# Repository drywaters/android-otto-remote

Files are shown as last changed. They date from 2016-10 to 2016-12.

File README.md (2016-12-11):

# OttoRemote

Piece Designs and other Additional Files - Includes the 3D design pieces supplied by Otto.strikingly.com.
Included in that directory is the Leg File that I designed and other documentation from their own website.

Otto_Arduino - Is the Arduino app that we created that uses the Bluetooth as a controller.

OTTO_smooth_criminal - Is an Arduino app created by somebody else that allows Otto to just dance.

The rest of the files is the actual Bluetooth app that works with BLUNO microcontrollers.

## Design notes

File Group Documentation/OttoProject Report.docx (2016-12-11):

Team Members:

Samuel Lum

Luan Dinh

Daniel Waters

Abstract

Title:

Otto the Robot

Problem:

Allow the user to remotely control a 3D printed Otto Robot using an Android app and a Bluetooth serial connection. The user is given options through the app to move forward, backwards, left, right, or play sound. The robot will sense objects in front of it, and refuse to move forward if something is within 5cm in front of it.

Techniques used:

1. Print the pieces of the robot using a 3D printer.
2. Wire electrical circuits to function correctly with an Arduino Mini microcontroller.
3. Allow the user to connect/disconnect to a Bluetooth radio in the Otto Robot through an Android application.
4. Once a command is received from the user, control the movements of the robot by 4 servo motors placed inside Otto.
5. Detect the distance in front of the robot using an ultrasonic sensor, and decide to move forward based on returned distance.
6. Allow Otto to make sound using a connected buzzer.
7. The Android application was written in Java using Android Studio, and the Arduino sketch was written in C/C++ using Arduino IDE.

Team Members:

Samuel Lum

Luan Dinh

Daniel Waters

Project: Otto the Robot

Objectives:

- Quick explanation of what the Otto the Robot is.
- Give a quick overview of how a 3D printer works.
- Explain how the Android application works.
- Use a GUI for the user to communicate with Otto
- Techniques used:
  - 3D design a new leg to connect correctly
  - 3D printed the parts
  - GUI for the Android application
  - Serial Bluetooth connection between phone and Arduino

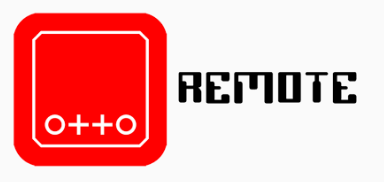
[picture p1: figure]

Otto the Robot is:

Otto, is an open source design for a robot found at http://otto.strikingly.com. The website supplies 3D printer design files for the pieces needed to build the robot and electrical wiring diagrams. It also includes a PDF that takes the user step by step in the build process. While the outer shell of Otto is given, the abilities for Otto is left up to the user to design themselves.

3D Design

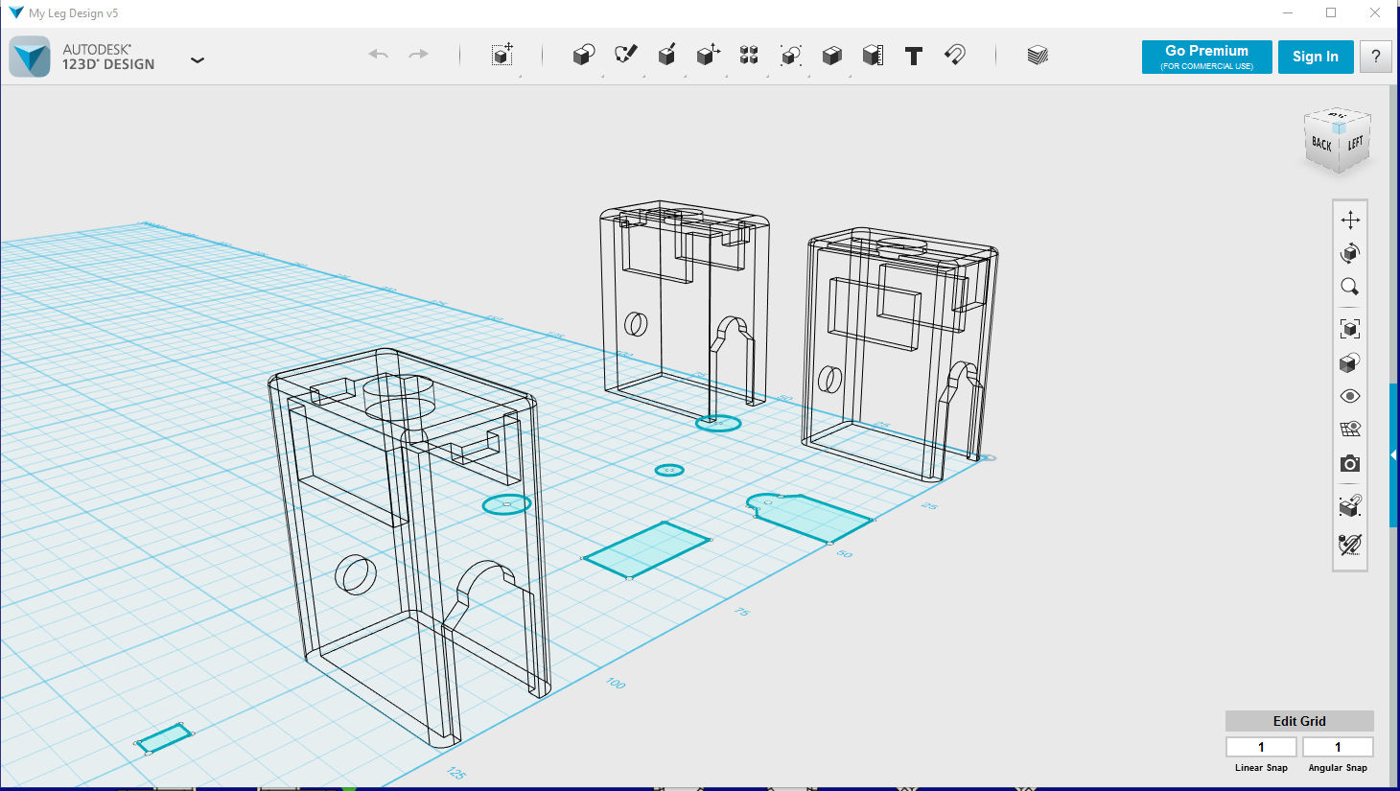
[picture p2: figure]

A 3D printer prints files that are designed in a 3D software such as Autodesk 123D Design. Inside this program a designer uses basic shapes to mold a shape into something that the printer would be able to understand. Example in this picture a simple box has pieces removed from it to form the shape of the newly designed Otto leg that will fit with the servos purchased. In the background are different versions of the leg that did not work correctly.

Once the figure is complete, it is exported to another software program that takes the 3D object and slices it into 100’s or 1000’s of tiny layers that the printer will use to build the object layer on layer. The program that I am using here is called FlashForge FlashPrint. For this simple leg at a standard quality it slices it down to 217 layers that needs to be printed.

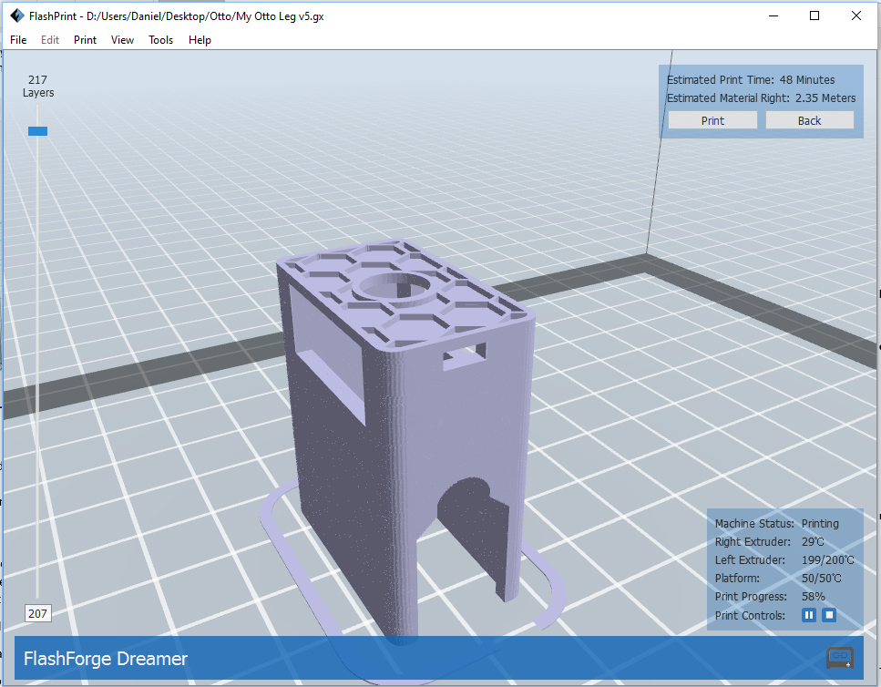
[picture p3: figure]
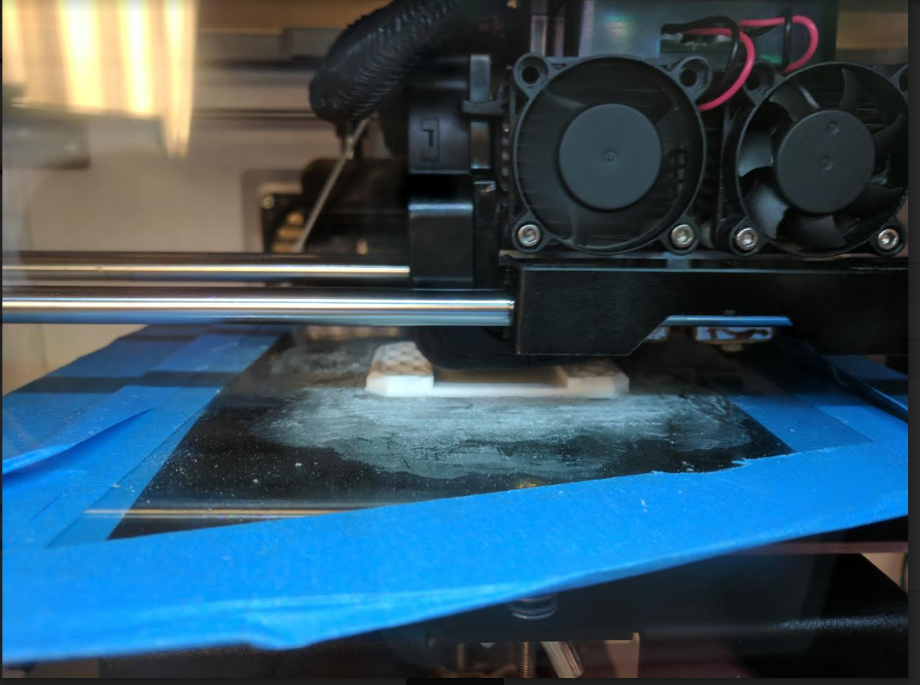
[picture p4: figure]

Finally, the printer understands the layers, and builds the object layer upon layer heating up plastic and printing them with small droplets of plastic.

Otto the Robot - Parts Schematic

Parts and Wiring Diagram for the Otto Robot

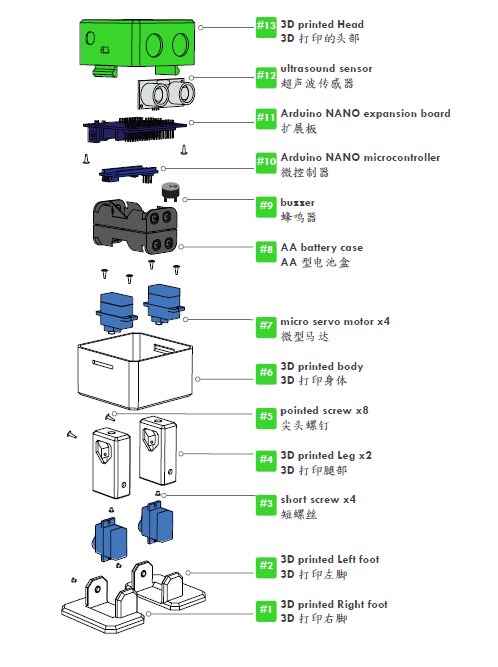
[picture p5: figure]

Otto the Robot – Wiring Diagram

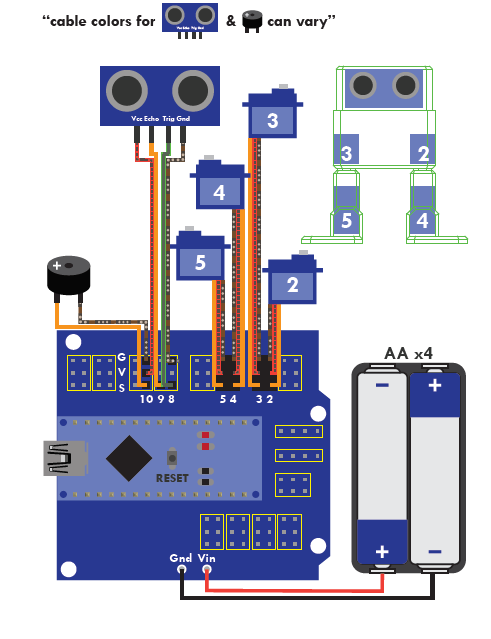
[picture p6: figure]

Parts Needed:

1x - Arduino Nano R3 Bluetooth embedded - https://www.dfrobot.com/index.php?route=product/product&product_id=1122 (https://www.google.com/url?amp;sa=D&amp;ust=1477184990057000&amp;usg=AFQjCNEKTpgmWJndd0WFRKf9GHzIdCvTMQ)

1x - Arduino Nano Shield I/O -

https://www.amazon.com/Solu-Expansion-Sensor-Arduino-Compatible/dp/B00UBEHJUO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 (https://www.google.com/url?amp;sa=D&amp;ust=1477184990058000&amp;usg=AFQjCNF9IKG_SzKIB6bwvJT9f6koBEpQsA)

1x - USB-A to Micro USB Cable -

https://www.amazon.com/gp/product/B012A1ML6W/ref=oh_aui_detailpage_o02_s00?ie=UTF8&psc=1 (https://www.google.com/url?amp;sa=D&amp;ust=1477184990059000&amp;usg=AFQjCNH3zjUvan4TNBtP3k6qlCdaCycngQ)

1x - HC-SR04 Ultrasound Sensor -

https://www.amazon.com/gp/product/B004U8TOE6/ref=oh_aui_detailpage_o03_s01?ie=UTF8&psc=1 (https://www.google.com/url?amp;sa=D&amp;ust=1477184990060000&amp;usg=AFQjCNFkso1mr9lOPCX5DlcGTcIGxcjSXw)

4x - Mini Servo SG90 9g -

https://www.amazon.com/gp/product/B01608II3Q/ref=oh_aui_detailpage_o03_s01?ie=UTF8&psc=1 (https://www.google.com/url?amp;sa=D&amp;ust=1477184990061000&amp;usg=AFQjCNHuSwTF9lRWxEb-zCN-XNy2eGt7uQ)

1x - Buzzer -

https://octopart.com/1536-adafruit+industries-61582119 (https://www.google.com/url?amp;sa=D&amp;ust=1477184990062000&amp;usg=AFQjCNFm4peGaZDmLa8tgEDlzYLoiwA7VA)

6x - Female/Female Jumper Wires -

https://octopart.com/266-adafruit+industries-28486657 (https://www.google.com/url?amp;sa=D&amp;ust=1477184990063000&amp;usg=AFQjCNGFNb7EBEjWObLrkJKwIMXw-9AAGg)

4xAA Battery Holder -

http://www.ebay.com/itm/122100190919?_trksid=p2057872.m2749.l2649&ssPageName=STRK%3AMEBIDX%3AIT

Android Application Design

Android applications are built with Java with some additional requirements needed to run on an Android device. Since the application requires user interaction, a GUI for the user is always required. These layout files are written in XML (Extensible Markup Language) and used by the Android application to display widgets for the user to interact with.

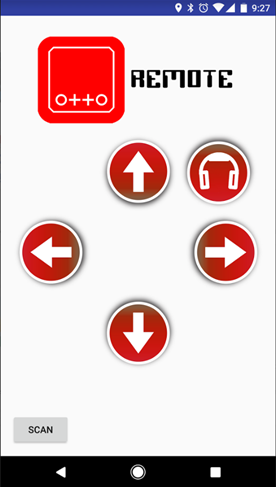
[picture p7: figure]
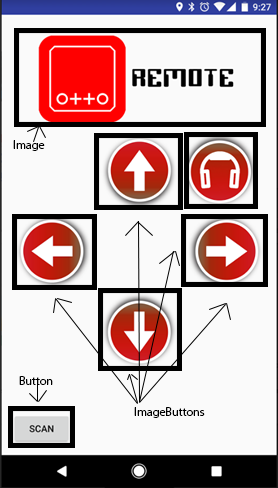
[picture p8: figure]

activity_otto_remote.xml

<RelativeLayout xmlns:android="http://schemas.android.com/apk/res/android"
xmlns:app="http://schemas.android.com/apk/res-auto"
xmlns:tools="http://schemas.android.com/tools"
android:layout_width="match_parent"
android:layout_height="match_parent"
android:focusable="true"
android:focusableInTouchMode="true"
android:paddingBottom="@dimen/activity_vertical_margin"
android:paddingLeft="@dimen/activity_horizontal_margin"
android:paddingRight="@dimen/activity_horizontal_margin"
android:paddingTop="@dimen/activity_vertical_margin"
tools:context=".OttoRemote">

<Button
android:id="@+id/buttonScan"
android:layout_width="wrap_content"
android:layout_height="wrap_content"
android:layout_alignParentBottom="true"
android:layout_alignParentLeft="true"
android:text="Scan"/>

<ImageButton
android:id="@+id/upButton"
android:layout_width="@dimen/button_width"
android:layout_height="@dimen/button_height"
android:layout_below="@+id/logo"
android:layout_centerHorizontal="true"
android:background="@drawable/up_selector"
android:scaleType="centerCrop"/>

<ImageButton
android:id="@+id/rightButton"
android:layout_width="@dimen/button_width"
android:layout_height="@dimen/button_height"
android:layout_alignParentRight="true"
android:layout_below="@id/upButton"
android:background="@drawable/right_selector"
android:scaleType="centerCrop"/>

<ImageButton
android:id="@+id/downButton"
android:layout_width="@dimen/button_width"
android:layout_height="@dimen/button_height"
android:layout_below="@id/rightButton"
android:layout_centerHorizontal="true"
android:background="@drawable/down_selector"
android:scaleType="centerCrop"/>

<ImageButton
android:id="@+id/leftButton"
android:layout_width="@dimen/button_width"
android:layout_height="@dimen/button_height"
android:layout_alignParentLeft="true"
android:layout_below="@id/upButton"
android:background="@drawable/left_selector"
android:scaleType="centerCrop"/>

<ImageButton
android:id="@+id/musicButton"
android:layout_width="@dimen/button_width"
android:layout_height="@dimen/button_height"
android:layout_toRightOf="@id/upButton"
android:layout_below="@id/logo"
android:background="@drawable/music_selector"
android:scaleType="centerCrop"/>

<ImageView
android:id="@+id/logo"
android:layout_width="300dp"
android:layout_height="160dp"
android:layout_alignParentTop="true"
android:layout_centerHorizontal="true"
android:scaleType="centerInside"
android:src="@drawable/otto_logo"/>

</RelativeLayout>

The company that produces the Bluno supplies a starter application that contains the necessary library files to connect and send serial data to the Bluno board. The java file, OttoRemote.java, connects the layout to the logic by using OnClickListeners to wait for users to interact with the, and then by extending the BlunoLibrary calls the method serialSend(STRING), that will send a character to the Bluno. Otto is then able to use a switch statement to act out a command based on the received character.

OttoRemote.java

package com.watersjournal.ottoremote;

import android.content.Intent;
import android.os.Bundle;
import android.view.View;
import android.view.View.OnClickListener;
import android.widget.Button;
import android.widget.EditText;
import android.widget.ImageButton;
import android.widget.TextView;

public class OttoRemote extends BlunoLibrary {
private Button buttonScan;
private Button buttonSerialSend;
private EditText serialSendText;
private TextView serialReceivedText;
private ImageButton buttonUp;
private ImageButton buttonDown;
private ImageButton buttonLeft;
private ImageButton buttonRight;
private ImageButton buttonMusic;
private long startTime;

@Override
protected void onCreate(Bundle savedInstanceState) {
startTime = System.currentTimeMillis();

super.onCreate(savedInstanceState);
setContentView(R.layout.activity_otto_remote);

onCreateProcess(); //onCreate Process by BlunoLibrary

serialBegin(115200); //set the Uart Baudrate on BLE chip to 115200

// Button to move Otto forward
buttonUp = (ImageButton) findViewById(R.id.upButton);
buttonUp.setOnClickListener(new OnClickListener() {
@Override
public void onClick(View view) {
long diff = System.currentTimeMillis() - startTime;
// Only send the command if the last one was over a second ago
// To allow Otto to finish the movement
if (System.currentTimeMillis() > startTime + 1000) {
serialSend("F");
startTime = System.currentTimeMillis();
}
}
});

// Button to move Otto backward
buttonDown = (ImageButton) findViewById(R.id.downButton);
buttonDown.setOnClickListener(new OnClickListener() {
@Override
public void onClick(View view) {
long diff = System.currentTimeMillis() - startTime;
// Only send the command if the last one was over a second ago
// To allow Otto to finish the movement
if (System.currentTimeMillis() > startTime + 1000) {
serialSend("B");
startTime = System.currentTimeMillis();
}
}
});

// Button to move Otto left
buttonLeft = (ImageButton) findViewById(R.id.leftButton);
buttonLeft.setOnClickListener(new OnClickListener() {
@Override
public void onClick(View view) {
long diff = System.currentTimeMillis() - startTime;
// Only send the command if the last one was over a second ago
// To allow Otto to finish the movement
if (System.currentTimeMillis() > startTime + 1000) {
serialSend("L");
startTime = System.currentTimeMillis();
}
}
});

// Button to move Otto right
buttonRight = (ImageButton) findViewById(R.id.rightButton);
buttonRight.setOnClickListener(new OnClickListener() {
@Override
public void onClick(View view) {
long diff = System.currentTimeMillis() - startTime;
// Only send the command if the last one was over a second ago
// To allow Otto to finish the movement
if (System.currentTimeMillis() > startTime + 1000) {
serialSend("R");
startTime = System.currentTimeMillis();
}
}
});

// Button to have Otto play some music
buttonMusic = (ImageButton) findViewById(R.id.musicButton);
buttonMusic.setOnClickListener(new OnClickListener() {
@Override
public void onClick(View view) {
long diff = System.currentTimeMillis() - startTime;
if (System.currentTimeMillis() > startTime + 1000) {
serialSend("M");
startTime = System.currentTimeMillis();
}
}
});

//initial the button for scanning the BLE device
buttonScan = (Button) findViewById(R.id.buttonScan);
buttonScan.setOnClickListener(new OnClickListener() {

@Override
public void onClick(View v) {
buttonScanOnClickProcess();//Alert Dialog for selecting the BLE device
}
});
}

protected void onResume(){
super.onResume();
System.out.println("BlUNOActivity onResume");
onResumeProcess(); //onResume Process by BlunoLibrary
}

@Override
protected void onActivityResult(int requestCode, int resultCode, Intent data) {
onActivityResultProcess(requestCode, resultCode, data); //onActivityResult Process by BlunoLibrary
super.onActivityResult(requestCode, resultCode, data);
}

@Override
protected void onPause() {
super.onPause();
onPauseProcess(); //onPause Process by BlunoLibrary
}

protected void onStop() {
super.onStop();
onStopProcess(); //onStop Process by BlunoLibrary
}

@Override
protected void onDestroy() {
super.onDestroy();
onDestroyProcess(); //onDestroy Process by BlunoLibrary
}

//Once connection state changes, this function will be called
@Override
public void onConectionStateChange(connectionStateEnum theConnectionState) {
switch (theConnectionState) { //Four connection states
case isConnected:
buttonScan.setText("Connected");
break;
case isConnecting:
buttonScan.setText("Connecting");
break;
case isToScan:
buttonScan.setText("Scan");
break;
case isScanning:
buttonScan.setText("Scanning");
break;
case isDisconnecting:
buttonScan.setText("isDisconnecting");
break;
default:
break;
}
}

//Once connection data received, this function will be called
@Override
public void onSerialReceived(String theString) {

}
}

Using Ultrasonic Sensor for Avoidance

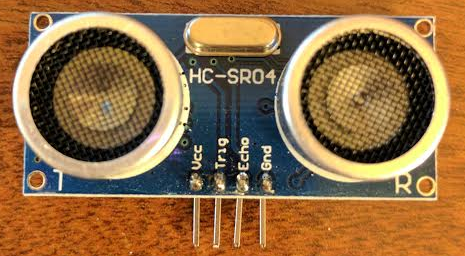
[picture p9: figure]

What is an Ultrasonic Sensor?

Active ultrasonic sensors generate high-frequency sound waves and evaluate the echo which is received back by the sensor, measuring the time interval between the sending signal and the receiving the echo is used to determine the distance to an object.

For more information see:

https://en.wikipedia.org/wiki/Ultrasonic_transducer

Demonstration of an ultrasonic sensor.

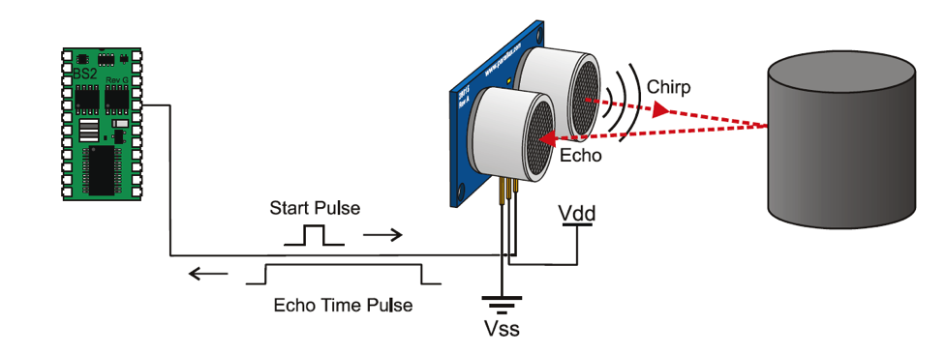
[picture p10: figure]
Image result for what is an ultrasonic sensor arduino

An ultrasonic sensor works just like how a bat or dolphin uses echo location. When the “Trig” side of the sensor receives 5Volts (HIGH), it begins to send out sound waves that are too high for humans to hear. After a very short period, about 10 microseconds, the sound waves are shut off. This tells the sensor to now begin to hear for the return of the sound waves through the “Echo” side of the sensor.

Arduino has a built-in function called pulseIn that will give the exact time difference between when the function is called and when the designated pin turns either HIGH or LOW. This calculated time is then used to calculate the distance traveled by the sound waves, using the simple formula, Distance = Time * Velocity (Of Sound Waves).

Code:

safeDistance Method

bool safeDistance() {

long duration, distance;

digitalWrite(trigPin, LOW); // Make sure not sending any sound

delayMicroseconds(2); // Clears the speaker for 2 microseconds

digitalWrite(trigPin, HIGH); // Start sound waves

delayMicroseconds(10); // Run for 10 microseconds

digitalWrite(trigPin, LOW); // Turn off sound waves

duration = pulseIn(echoPin, HIGH); // Set the echo pin to wait till receive 5V

distance = (duration/2) * 0.03435; // Calculate the distance by formula

// (Distance = Speed * Time)

// Time / 2 because do not want the time from // the object and back

// We only want the time to the object.

// 0.03435 is the speed of sound in CM/S^2

return (distance > 5);

}

Tone

Hardware:

Piezo Speaker: uses a material that’s piezoelectric, it can changes shape when you apply electric to it. By adhering a piezo-electric disc to a thin metal plate, and the applying electricity, we can bend the metal back and forth, which in turn creates noise.

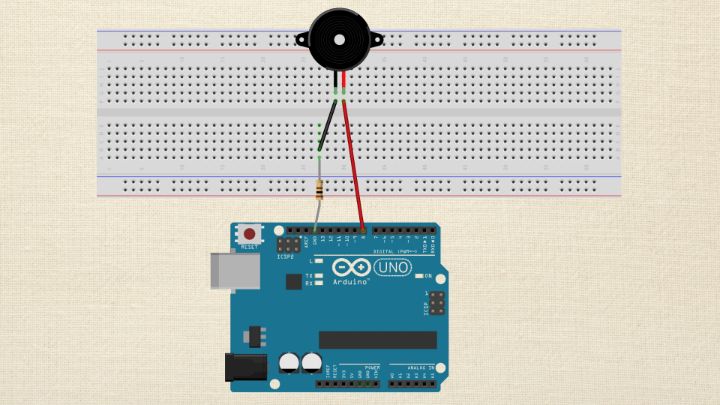
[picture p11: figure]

Otto robot (already build in)

Tone() function

Syntax

Tone needs 2 arguments, but it can take 3

Tone(pin, frequency)

Tone(pin, frequency, duration)

Parameters

*Pin Number: the pin that to geberate the tone

*Frequency: it is specified in hertz. Hertz are cycles per second. Unsigned int

*Duration: how long you want a tone to play. It is in milliseconds.

Return

Nothing

Here is an example of tone() function

Tone(10, 1000, 500)

Pin number: 10

Frequency: 1000

Duration: 500

Notes: The frequency is an unsigned integer and can take value up to 65,535-but if you are trying to make tones for a human ear, then values between 2000-5000 are where our ears are most tunes.

If you want to break a tone you can use delay() function

Tone() function uses one of the built in times on the Arduino’s micro-controller.

Tone() function works independently of the delay() function.

Tone() function limits

Cannot generate a tone lower than 31hz. You can pass values 31 and less to the tone() function, but it does not mean you will get a good representation of it.

Tone() function cannot be used by two separated pins at the same time

void playMusic() {

for(int i=0; i < MAX_COUNT; i++) {

tone_ = melody[i];

beat = 50;

duration = beat * tempo; // Set up timing

playTone();

// A pause between notes...

delayMicroseconds(pause);

}

}

Servomotors for Walking

What is a Servomotor?

A servo is motor that has a rotor that can be controlled between 0 and 180 degrees. The precise angle, velocity and acceleration of the servomotor can be defined. Our servomotors are attached via three wires: power (Vcc), ground (Gnd) and signal (Pulse). The functions provided in the default Arduino library to pair the motor are attach(), write(), detach().

Demonstration of Servomotor wiring configuration

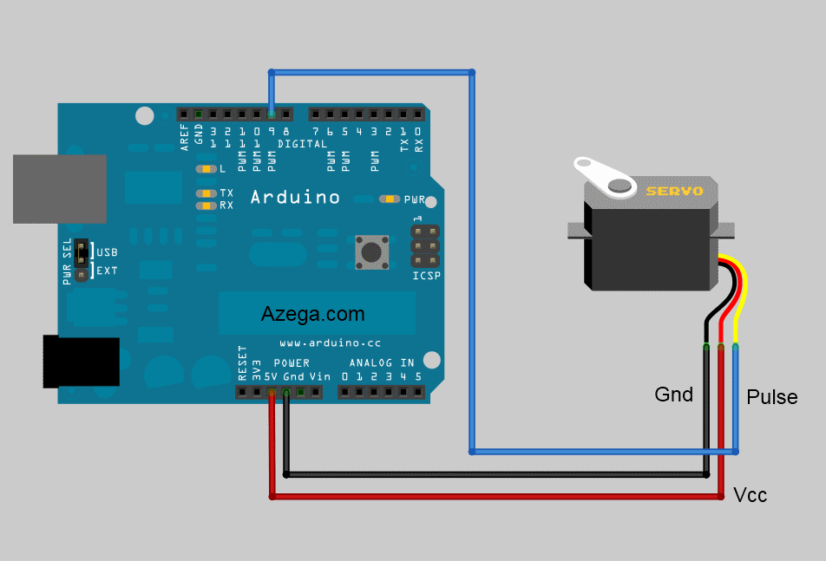
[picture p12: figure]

The attach() and detach() function pairs one servo motor with a signal pin on the microcontroller. When the pin outputs a signal, it sends a sinusoidal wave through the signal wire. The program written adjusts the 4 dimensions of a wave:

Amplitude (degrees), Period (mS) , Phase (radians) and Offset (degrees)

A signal emitted from the microcontroller tells each servo what angle the servo should move, in what order and for how long. Each servomotor represents one joint in robot’s leg. The collective effort of the four servomotors propels the robot in the desired direction.

Otto_Arduino.ino

#include <Servo.h>

#include "Oscillator.h"

#include <EEPROM.h>

#define N_SERVOS 4

//-- First step: Configure the pins where the servos are attached

/*

| O O |

YR 3==> | | <== YL 2

RR 5==> ----- ------ <== RL 4

*/

#define TRIM_RR 7

#define TRIM_RL 4

#define TRIM_YR 4

#define TRIM_YL -7

//OTTO.setTrims(-7,-4,-4,7);

#define PIN_RR 5

#define PIN_RL 4

#define PIN_YR 3

#define PIN_YL 2

#define C 2100

#define D 1870

#define E 1670

#define f 1580

#define G 1400

#define R 0

#define INTERVALTIME 10.0

Oscillator servo[N_SERVOS];

const int trigPin = 9;

const int echoPin = 8;

const int speakerOut = 10;

// function prototypes

void turnLeft(int steps, int T=3000);

void turnRight(int steps, int T=3000);

void walk(int steps, int T=1000);

void backyard(int steps, int T=3000);

bool safeDistance();

void playMusic();

int melody[] = {E,E,E,R,E,E,E,R,E,G,C,D,E,R,f,f,f,f,f,E,E,E,E,D,D,E,D};

int MAX_COUNT = sizeof(melody) / 2; // Melody length, for looping.

// Set overall tempo

long tempo = 7500;

// Set length of pause between notes

int pause = 1000;

// Loop variable to increase Rest length

int rest_count = 70;

// Initialize core variables

int tone_ = 0;

int beat = 0;

long duration = 0;

void setup() {

// put your setup code here, to run once:

Serial.begin(115200);

servo[0].attach(PIN_RR);

servo[1].attach(PIN_RL);

servo[2].attach(PIN_YR);

servo[3].attach(PIN_YL);

servo[0].SetTrim(TRIM_RR);

servo[1].SetTrim(TRIM_RL);

servo[2].SetTrim(TRIM_YR);

servo[3].SetTrim(TRIM_YL);

pinMode(trigPin, OUTPUT);

pinMode(echoPin, INPUT);

pinMode(speakerOut, OUTPUT);

for(int i=0;i<4;i++) servo[i].SetPosition(90);

}

// TEMPO: 121 BPM

int t=495;

void loop() {

// put your main code here, to run repeatedly:

if(Serial.available()) {

char character = Serial.read();

switch(character) {

case 'F':

Serial.println("MOVING OTTO UP");

if (safeDistance()) {

walk(2, t*2);

} else {

tone(10, 440, 1000);

}

break;

case 'B':

Serial.println("MOVING OTTO DOWN");

tone(13, 800, 100);

back(2, t*2);

break;

case 'L':

Serial.println("MOVING OTTO LEFT");

turnLeft(2, t*2);

break;

case 'R':

Serial.println("MOVING OTTO RIGHT");

turnRight(2, t*2);

break;

case 'M':

Serial.println("PLAYING MUSIC");

playMusic();

break;

}

}

}

void oscillate(int A[N_SERVOS], int O[N_SERVOS], int T, double phase_diff[N_SERVOS]){

for (int i=0; i<4; i++) {

servo[i].SetO(O[i]);

servo[i].SetA(A[i]);

servo[i].SetT(T);

servo[i].SetPh(phase_diff[i]);

}

double ref=millis();

for (double x=ref; x<T+ref; x=millis()){

for (int i=0; i<4; i++){

servo[i].refresh();

}

}

}

void back(int steps, int T){

int A[4]= {15, 15, 30, 30};

int O[4] = {0, 0, 0, 0};

double phase_diff[4] = {DEG2RAD(0), DEG2RAD(0), DEG2RAD(90), DEG2RAD(90)};

for(int i=0;i<steps;i++)oscillate(A,O, T, phase_diff);

}

void walk(int steps, int T){

int A[4]= {15, 15, 30, 30};

int O[4] = {0, 0, 0, 0};

double phase_diff[4] = {DEG2RAD(0), DEG2RAD(0), DEG2RAD(-90), DEG2RAD(-90)};

for(int i=0;i<steps;i++)oscillate(A,O, T, phase_diff);

}

void turnLeft(int steps, int T){

int A[4]= {20, 20, 10, 30};

int O[4] = {0, 0, 0, 0};

double phase_diff[4] = {DEG2RAD(0), DEG2RAD(0), DEG2RAD(90), DEG2RAD(90)};

for(int i=0;i<steps;i++)oscillate(A,O, T, phase_diff);

}

void turnRight(int steps, int T){

int A[4]= {20, 20, 30, 10};

int O[4] = {0, 0, 0, 0};

double phase_diff[4] = {DEG2RAD(0), DEG2RAD(0), DEG2RAD(90), DEG2RAD(90)};

for(int i=0;i<steps;i++)oscillate(A,O, T, phase_diff);

}

bool safeDistance() {

long duration, distance;

digitalWrite(trigPin, LOW); // Make sure not sending any sound

delayMicroseconds(2); // Clears the speaker for 2 microseconds

digitalWrite(trigPin, HIGH); // Start sound waves

delayMicroseconds(10); // Run for 10 microseconds

digitalWrite(trigPin, LOW); // Turn off sound waves

duration = pulseIn(echoPin, HIGH); // Set the echo pin to wait till receive 5V

distance = (duration/2) * 0.03435; // Calculate the distance by formula (Distance = Speed * Time)

// Time / 2 because do not want the time from the object and back

// We only want the time to the object.

// 0.03435 is the speed of sound in CM/S^2

return (distance > 5);

}

void playTone()

{

long elapsed_time = 0;

if(tone_ > 0) { // if this isn't a Rest beat, while the tone has

// played less long than 'duration', pulse speaker HIGH and LOW

while(elapsed_time < duration) {

digitalWrite(speakerOut,HIGH);

delayMicroseconds(tone_ / 2);

// DOWN

digitalWrite(speakerOut, LOW);

delayMicroseconds(tone_ / 2);

// Keep track of how long we pulsed

elapsed_time +=(tone_);

}

}

else

{

// Rest beat; loop times delay

for(int j = 0; j < rest_count; j++)

{

delayMicroseconds(duration);

}

}

}

void playMusic() {

for(int i=0; i < MAX_COUNT; i++) {

tone_ = melody[i];

beat = 50;

duration = beat * tempo; // Set up timing

playTone();

// A pause between notes...

delayMicroseconds(pause);

}

}

Conclusion:

In this project, it was a totally new experience for us all. None of us had worked with Arduino boards before, and we all had a limited understanding of the electrical circuitry. The online guide was a big help to get us started with the prefabricated 3D models and electrical wiring diagrams. Ultimately, we wanted to alter the design with our code by adding additional features.

We learned several things in creation of this robot including:

1. We learned how servos worked and how to control them by sending different electrical signals to drive the motors.
2. We learned how to create an Android app, and how to work with the Bluno libraries that were included for this Arduino board. We also learned how to control an Arduino through a Bluetooth serial interface.
3. We learned how an Arduino functions and some understanding of electrical circuits.

Things that we would have done differently:

1. Better calibrate his movements so that he moves better.
2. Adding additional hardware to Otto like a power switch or lights.

Issues that we encountered:

1. Making the pre-designed pieces work was an issue because they did not fit perfectly. This took a lot longer than expected, but we got them to fix after altering them.
2. Biggest issue at the beginning was that the leg model that was provided did not fit the servos that we purchased. This was a slow process because 3D printing each leg took around 30 minutes for each leg. Eventually, we had to design our own leg to make it work correctly.
3. One of the ultrasonic sensors did not function correctly, and we originally thought that our code was wrong. Only by testing with a known good sensor did we finally realize that the sensor was actually bad.

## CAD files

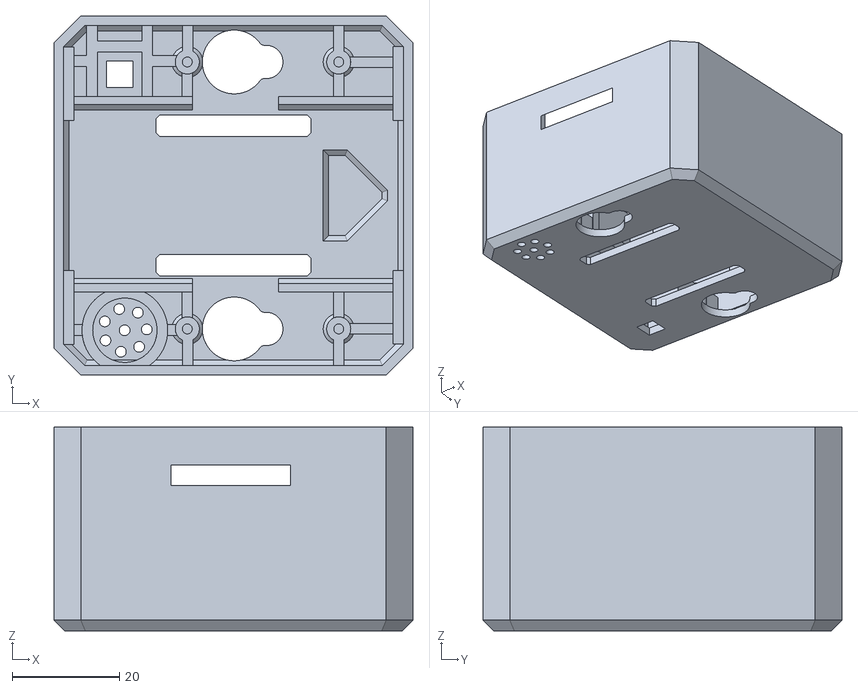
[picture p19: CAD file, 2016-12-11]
Piece Designs and other Additional Files/OTTO_body_v3.stl
67.0 x 67.0 x 38.0

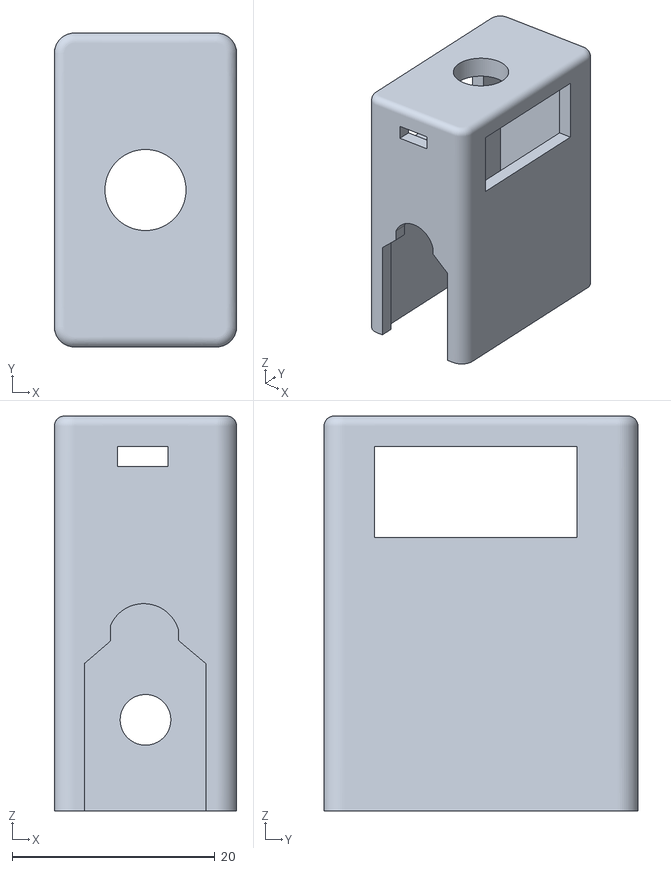
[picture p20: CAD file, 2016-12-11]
Piece Designs and other Additional Files/Daniel - My Otto Leg v5.stl
18.0 x 31.0 x 39.0

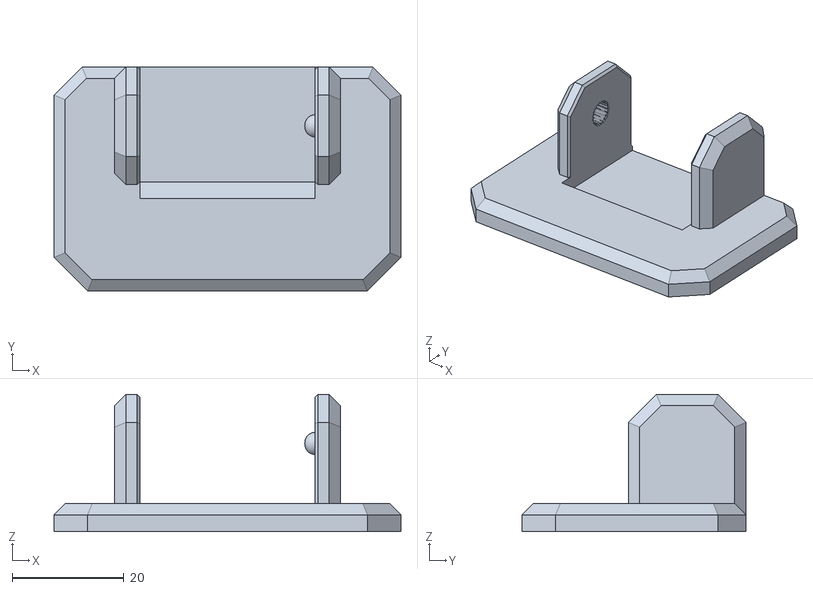
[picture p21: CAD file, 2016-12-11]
Piece Designs and other Additional Files/OTTO_footR_v2.stl
62.0 x 40.0 x 24.5

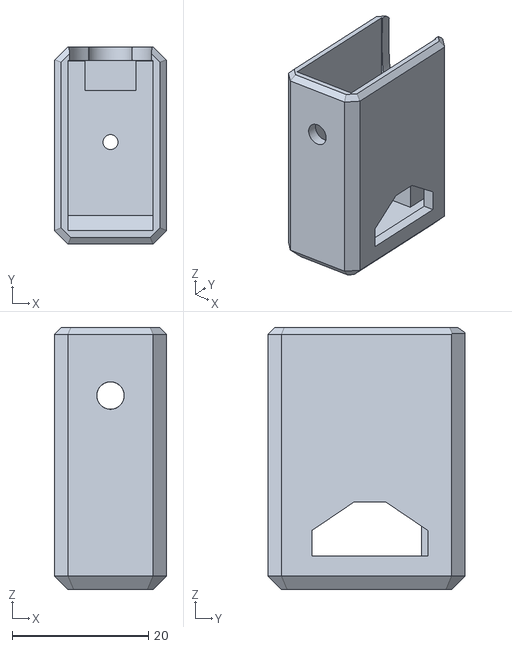
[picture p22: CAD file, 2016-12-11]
Piece Designs and other Additional Files/OTTO_leg_v3.stl
16.5 x 29.0 x 38.5

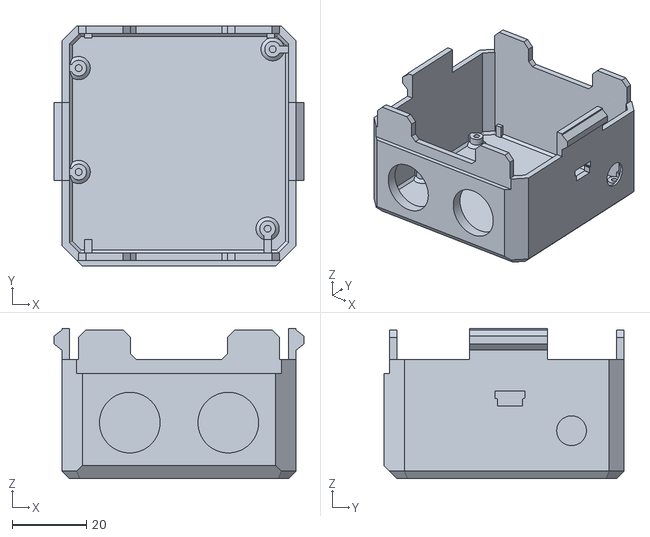
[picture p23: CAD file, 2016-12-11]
Piece Designs and other Additional Files/OTTO_head_v3.stl
67.2 x 64.5 x 40.4

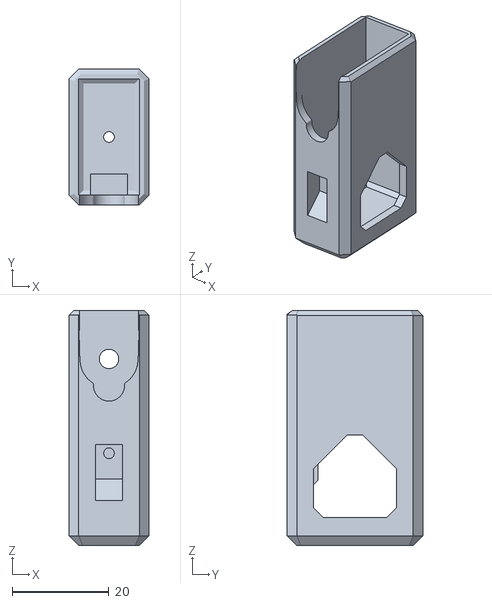
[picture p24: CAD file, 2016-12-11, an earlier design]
Piece Designs and other Additional Files/OTTO_leg_v2.stl
16.5 x 28.0 x 48.5

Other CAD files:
Piece Designs and other Additional Files/OTTO_footL_v2.stl

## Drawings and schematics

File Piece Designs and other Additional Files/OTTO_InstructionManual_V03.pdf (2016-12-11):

## DIY

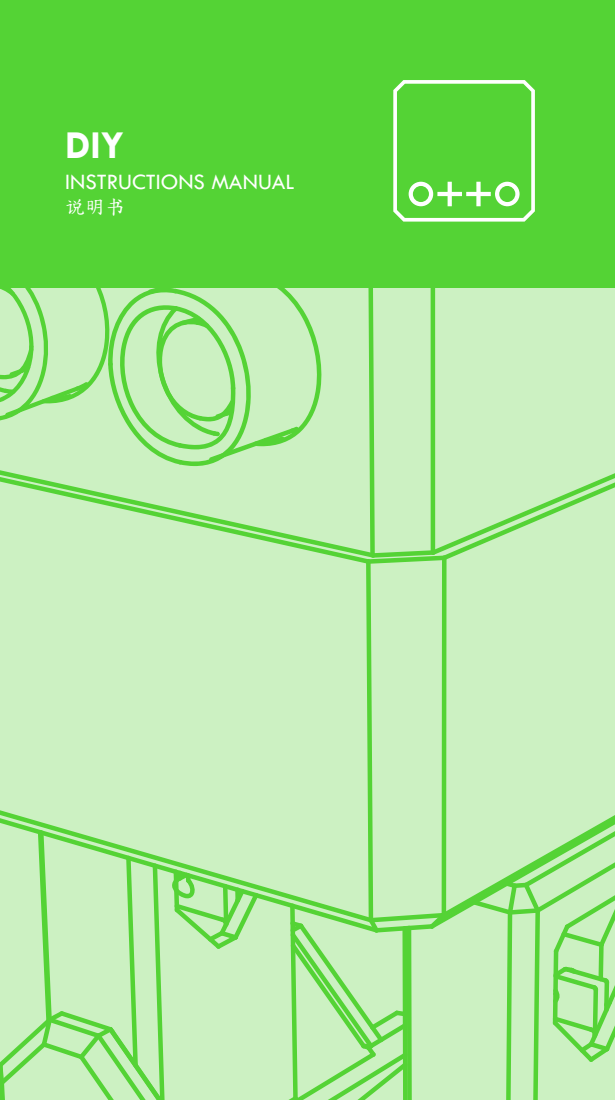
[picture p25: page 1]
INSTRUCTIONS MANUAL 说明书

## DIY

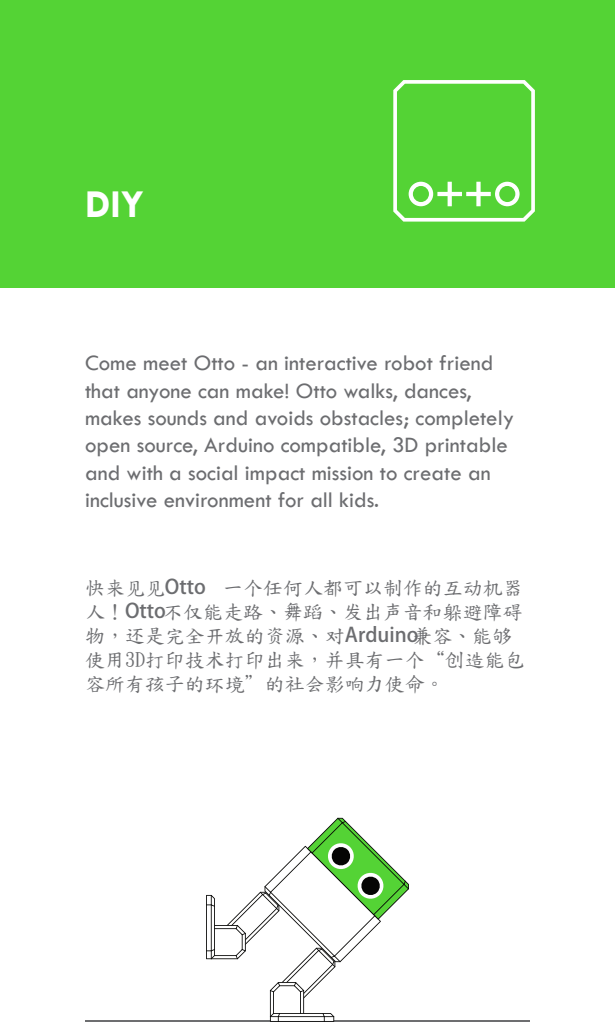
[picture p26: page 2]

Come meet Otto - an interactive robot friend
that anyone can make! Otto walks, dances,
makes sounds and avoids obstacles; completely
open source, Arduino compatible, 3D printable
and with a social impact mission to create an
inclusive environment for all kids.

快来见见Otto 一个任何人都可以制作的互动机器
人！Otto不仅能走路、舞蹈、发出声音和躲避障碍
物，还是完全开放的资源、对Arduino兼容、能够
使用3D打印技术打印出来，并具有一个“创造能包
容所有孩子的环境＂的社会影响力使命。

## PARTS

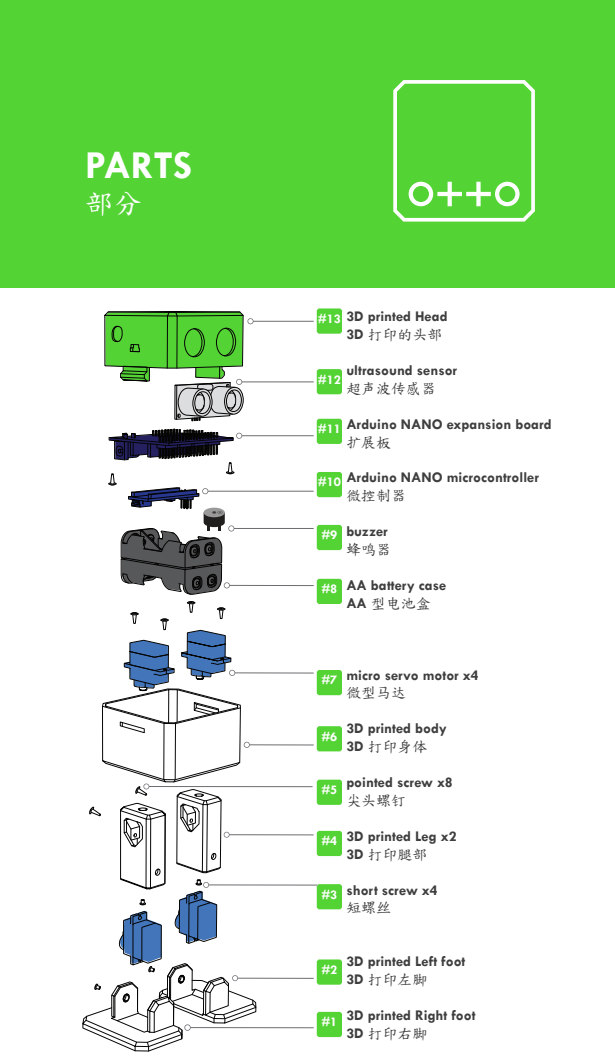
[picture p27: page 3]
3D printed Head 3D 打印的头部; ultrasound sensor 超声波传感器; Arduino NANO microcontroller 微控制器; buzzer 蜂鸣器; micro servo motor x4 微型马达; 3D printed body 3D 打印身体; pointed screw x8 尖头螺钉; 3D printed Leg x2 3D 打印腿部; short screw x4 短螺丝; 3D printed Left foot 3D 打印左脚

Arduino NANO expansion board
扩展板

AA battery case
AA 型电池盒

3D printed Right foot
3D 打印右脚 #1

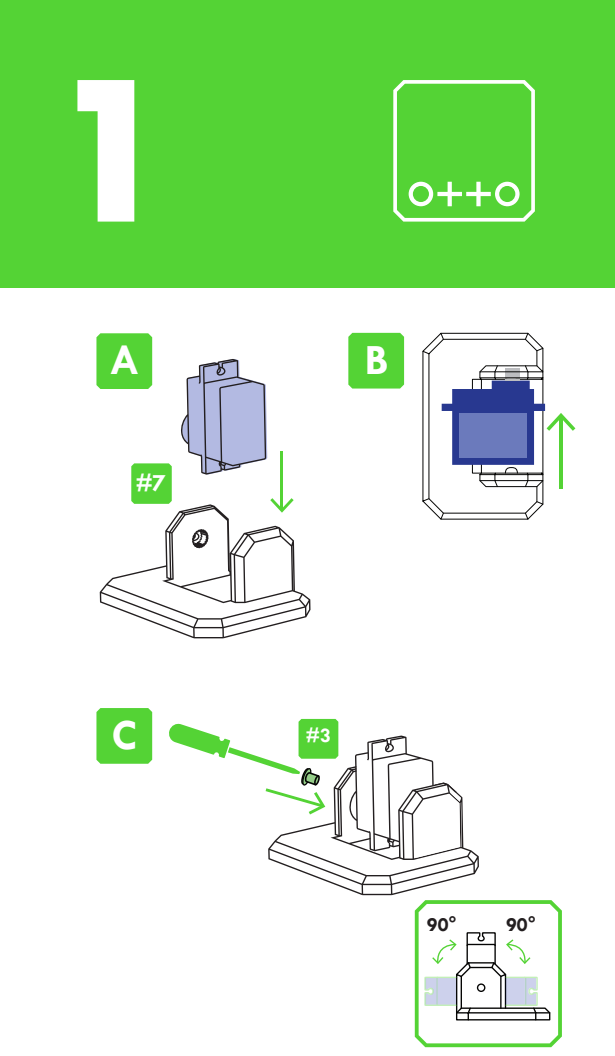
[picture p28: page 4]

2

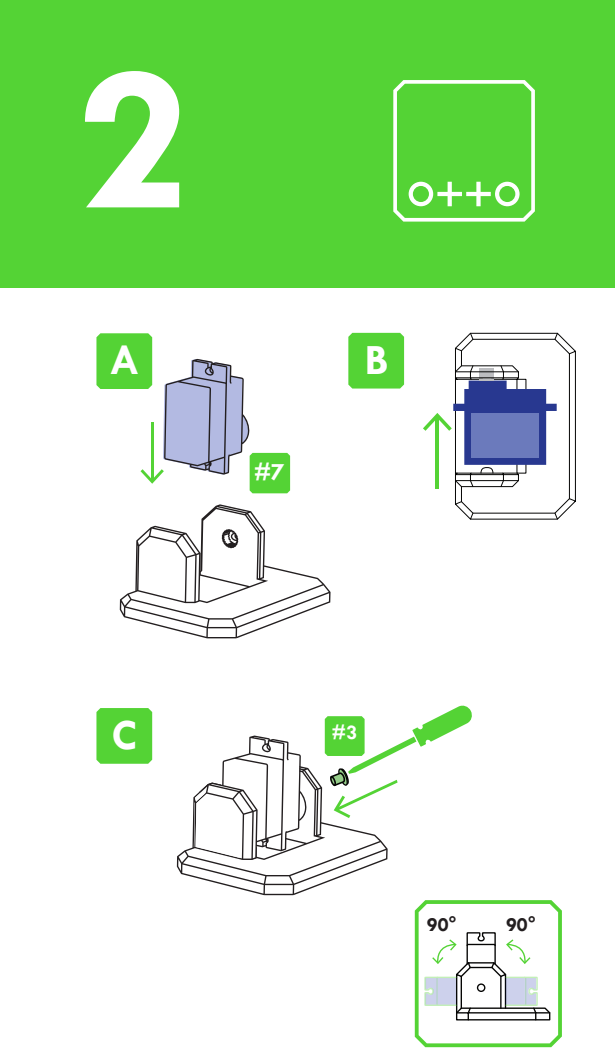
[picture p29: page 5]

3

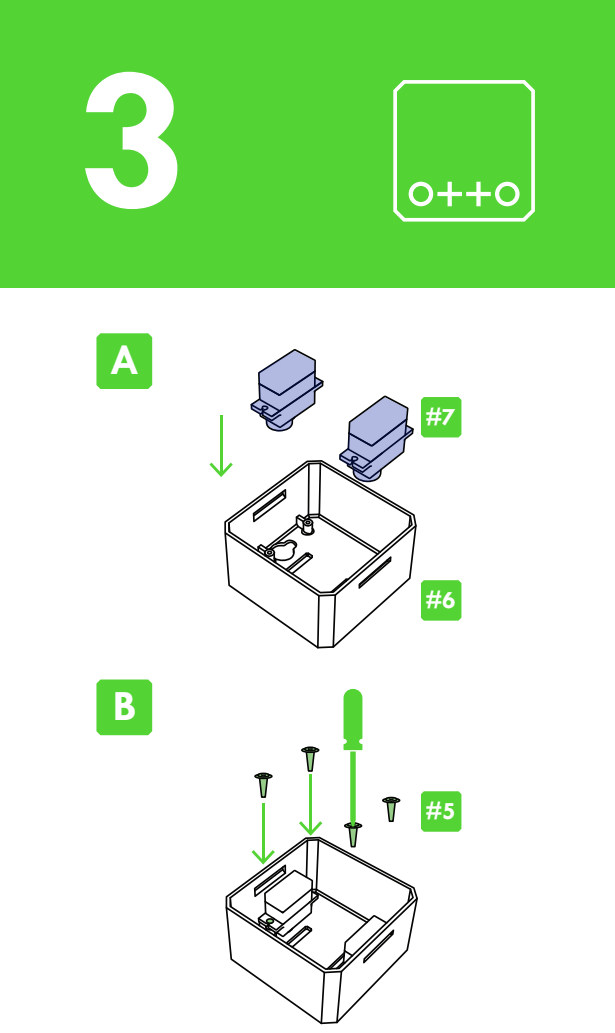
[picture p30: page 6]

4AB

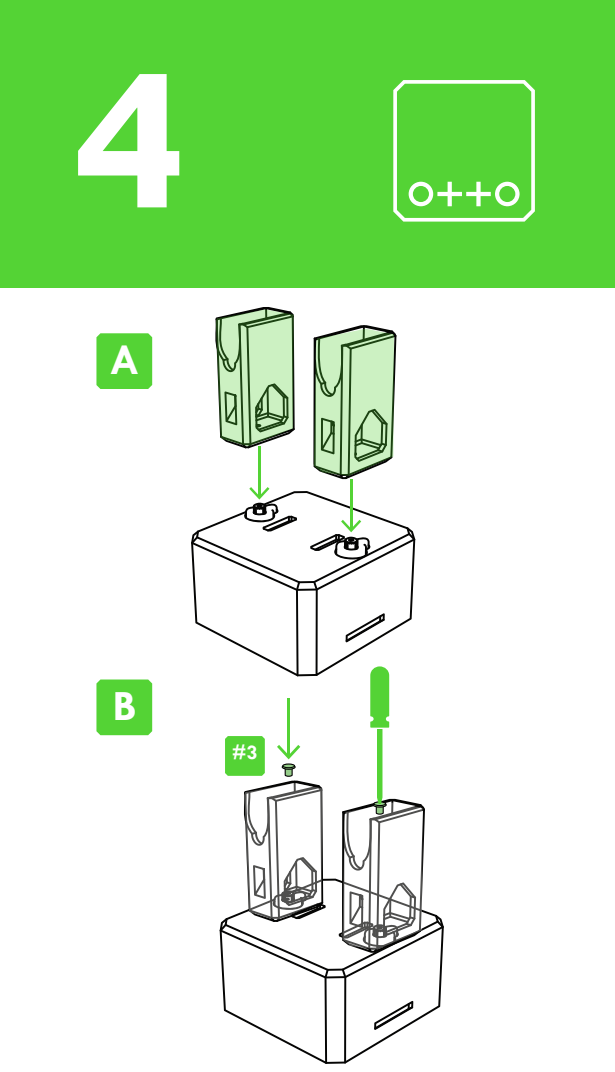
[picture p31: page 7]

5AB

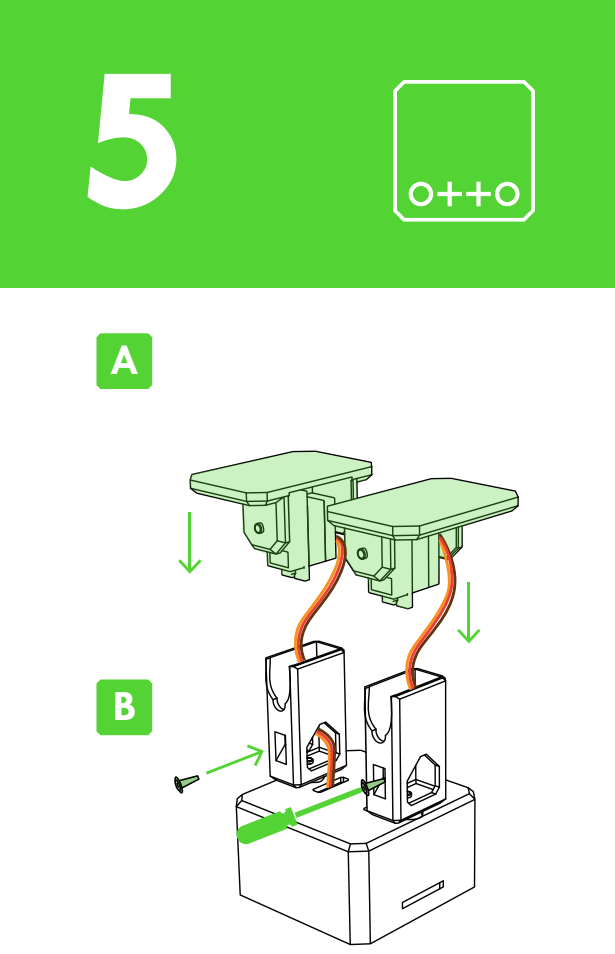
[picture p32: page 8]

6

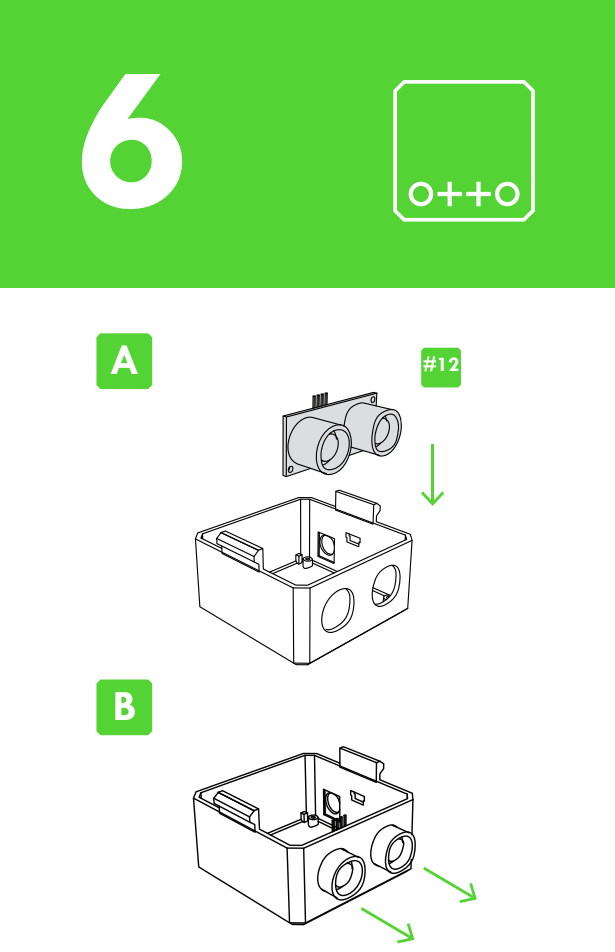
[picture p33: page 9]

7

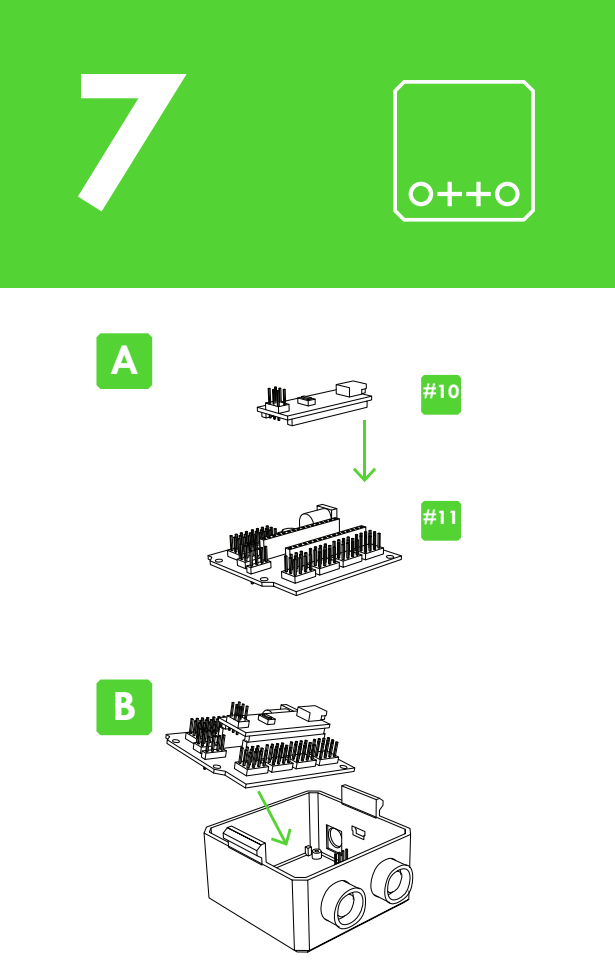
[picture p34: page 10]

8

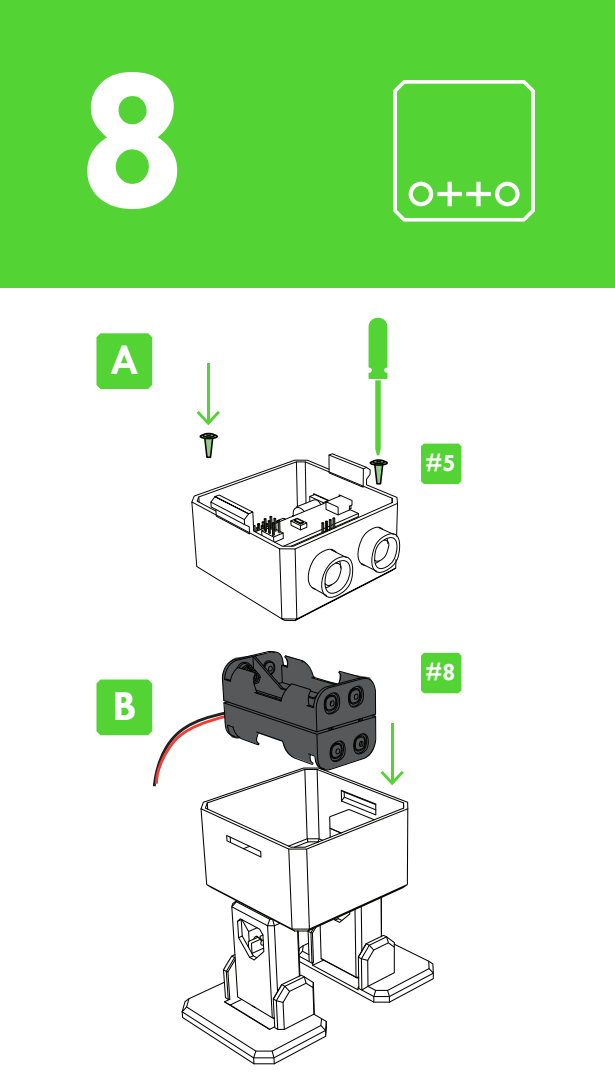
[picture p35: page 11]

9

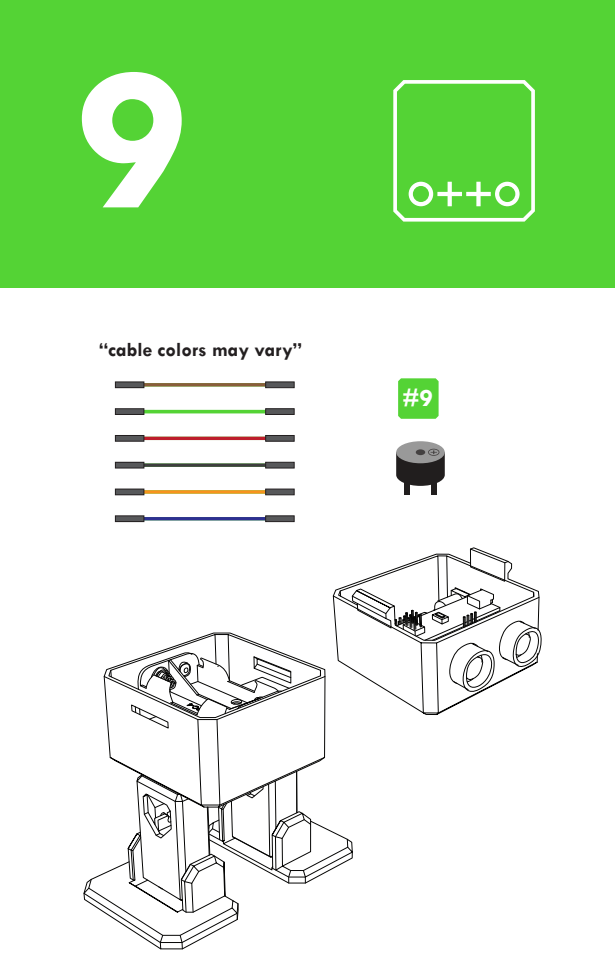
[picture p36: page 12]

“cable colors may vary”

10

RESET; Gnd Vin; “cable colors for; can vary” Vcc Echo Trig Gnd

Vcc Echo Trig Gnd

11


12

© 2016 OTTO

打造你自己的机器人
build your own robot

### ottobot.org

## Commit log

2016-10-29 Added a starting Arduino File
2016-12-11 Added 3D Design Pieces, and my own Leg Design. Also, includes the Otto documentation from Otto.strikingly.com.
    [Daniel - My Otto Leg v5.stl, OTTO_body_v3.stl, OTTO_footL_v2.stl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]
